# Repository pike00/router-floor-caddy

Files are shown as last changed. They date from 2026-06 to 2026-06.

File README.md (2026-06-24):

---
title: "Router Floor Caddy — Xfinity XB8 + Netgear Orbi RBR850"
description: "A well-ventilated, floor-standing caddy that holds two hot-running networking towers upright, with a bay for incoming-cable entry (\"cabinet input\") and storage (power bricks, cable…"
date: 2026-06-05
version: v3.2
tags: [organization, electronics, storage]
material: PETG / PLA
print: { layer_height: 0.2mm, infill: 20%, supports: false }
license: CC-BY-NC-4.0
showcase: false
source: private
---

# Router Floor Caddy — Xfinity XB8 + Netgear Orbi RBR850

A well-ventilated, floor-standing caddy that holds two hot-running networking
towers upright, with a bay for incoming-cable entry ("cabinet input") and
storage (power bricks, cable slack). Honeycomb-vented walls, open tops.

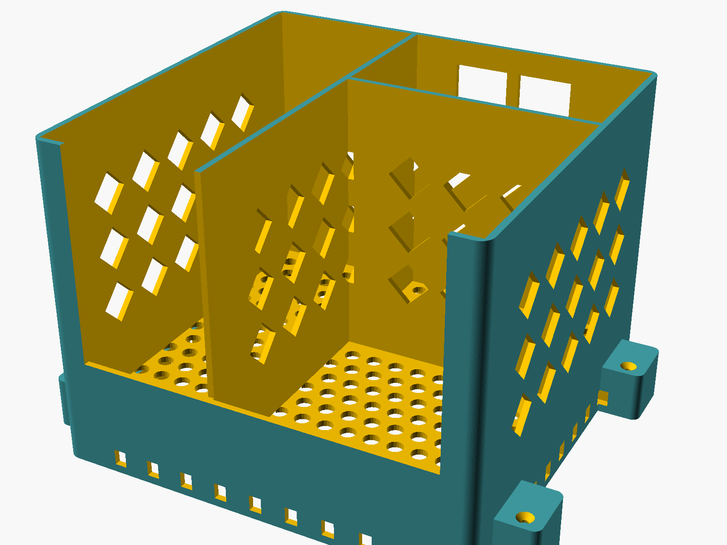
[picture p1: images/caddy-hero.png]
caddy


## Two parts: body + floor-mount base

Prints as **two parts** (both fit a 256 mm bed):

- **`caddy-body.stl`** — the caddy shell with three internal bays (the box).
- **`caddy-base.stl`** — a low vented ring that screws to the floor; the body
  drops onto it and screws down separately, so the body is removable while the
  base stays floor-mounted.

**Installation:** screw the base to the floor through the 4 corner ears
(countersunk #8 holes). Set the body on the base — its 4 corner ears drop over
the base's **conical alignment posts** (the cones self-center the body). Drive an
M3 screw down through each body ear into the post (self-tapping pilot). To remove
the body later, back out the 4 M3 screws; the base stays put.
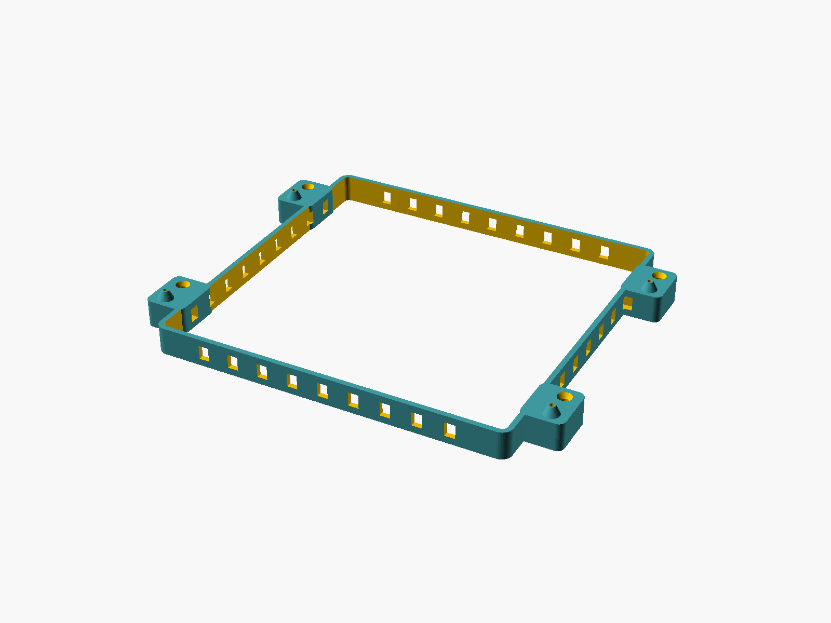
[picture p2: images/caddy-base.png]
base


The whole joint is **support-free**: the cones self-support (sloped walls),
holes are vertical, and every countersink opens upward.

## The box

The body is a single shell with three internal bays, footprint **206 × 200 mm**
(246 mm across the mount ears), ~143 mm tall.

The trick that makes one piece possible: the two routers side-by-side would span
117 + 190 = 307 mm (over the bed), so the **Orbi is rotated 90°** — its thin
72 mm edge faces sideways instead of its 190 mm face. Both towers plus a storage
bay then pack into 206 × 200 mm. The storage/cable bay tucks into the depth gap
behind the shorter XB8:

```
 plan view (one shell, ~206 x 200 mm):
 +-----------+------------------+
 |           |   XB8 bay        |  front wall lowered (drop-in access)
 |  Orbi bay | ports v 117x117  |
 | (rotated) +---[pass]---------+   <- XB8 cables drop into storage
 | ports >   | storage + cable  |  back wall: cable-entry notch
 |  72 x 190 |   ^ Orbi cables  |
 +-----------+------------------+
   ports > = Orbi back face points at divider; cable passes into storage
```

## The two devices (measured / datasheet)

| Device | Footprint (W × D) | Height | Shape |
|---|---|---|---|
| Xfinity **XB8** gateway | ~117 × 117 mm | ~218 mm | square rounded-base tower |
| Netgear **Orbi RBR850** | ~190 × 72 mm | ~280 mm | tall leaf/egg tower |

Sources: the [HIDEit XB8 mount](https://hideitmounts.com/products/hideit-xb8-xfinity-xb8-gateway-modem-mount)
cradle is 120 mm square (confirming the ~117 mm XB8 base); Orbi dimensions are
from the Netgear RBK850 datasheet (11.02 × 7.50 × 2.81 in). Each bay is a
rectangular pocket sized to the device footprint + 2 mm clearance per side; the
Orbi's curved leaf sits loosely in its rectangular pocket (add a strip of foam if
you want a snug grip). No floor-caddy STL for these exists online — every hit is
a *wall* mount (e.g. [XB8](https://www.printables.com/model/414508-xfinity-gateway-xb8-wall-mount),
[Orbi](https://www.printables.com/model/48893-orbi-mount-for-rbr850-router-and-satellite)) —
so this is modeled from dimensions, not remixed.

Each bay grips only the lower ~half of its tower; the towers protrude above the
open tops, fully exposed for cooling. The **front wall is lowered to 35 mm** for
cable/port access and heat relief.

## Ventilation

- Hex-staggered perforated **floor** under every bay.
- **12 mm raised feet** → an open air gap under the whole caddy so air enters
  from below and rises through the floor holes and open tops.
- **Diagonal-lattice vents** (45° diamond openings) across the outer side/back
  walls AND both internal divider walls, so air (and cables) move freely between
  all three bays. Every opening peaks at 45°, so the walls have **no horizontal
  bridges at all** — the most support-free vent pattern.
- The **base ring** is slot-vented; air enters its sides, rises through the
  body's hex floor and out the open tops.
- **Open tops**; towers stand exposed above the shell line.

## Cable input + storage + router orientation

The central rear bay is the **cabling hub**. It has a **cable window in the back wall** (closed at the top by a rim bar so the wall sections beside it are tied together, not free-topped flaps)
for incoming coax/ethernet (the "cabinet input") and holds power bricks,
splitters, and cable slack.

**Both routers face their port (back) sides into this bay:**

- The **Orbi** is rotated so its port/broad face points at the **+X divider**;
  a low cable pass-through in that divider drops its cables into the storage bay.
- The **XB8** faces its ports at the **+Y divider** into the same bay through a
  matching low pass-through.

So every cable runs into the central bay and out the rear notch — nothing is
boxed against an outer wall. Directionality note: rotating the Orbi about its
vertical axis does **not** affect cooling (convection is bottom-to-top) or WiFi,
but it does move its port/vented broad face — hence the deliberate
divider-facing layout and the extra vents cut into the divider beside it.

## Printing

- **Material: PETG** recommended — it sits on a floor next to two warm devices;
  PETG tolerates heat far better than PLA. PLA works if the room stays cool.
- 0.2 mm layers, 15–20 % infill, 3 walls.
- **No supports needed** — walls are vertical; hexagons, hex floor holes, and the
  cable window all bridge fine; the base slots are tiny bridges.
- Print as exported: each part floor-down, open side up.
- Two prints (body + base), each ~246 × 200 mm — fit a 256 mm bed.
- **Hardware:** 4 × #8 wood/floor screws (base → floor) + 4 × M3 × ~12 mm
  self-tapping screws (body → base posts).

## Build

```sh
just build      # export caddy-body.stl + caddy-base.stl
just preview    # re-render the PNGs in images/  (uses xvfb-run)
just clean      # remove generated STLs
```

`src/caddy.scad` is the parametric source of truth — every dimension is a named
parameter at the top (device footprints, clearance, wall/shell height, storage
depth, vent sizing, and the base/ear/screw dimensions). `part="body"|"base"|
"assembly"` selects what to emit; change a parameter and re-run `just build`.

## Versions

- **v3.2** — wall + divider vents switched from honeycomb to a **45° diagonal
  lattice** (diamond openings). Every opening peaks at 45°, so there are no
  horizontal bridges — the most support-free vent pattern.
- **v3.1** — fully support-free: the body↔base joint uses **conical self-centering
  posts** (no blind sockets/overhangs); the cable window gets a center mullion so
  its rim is a short bridge; and **both internal divider walls are honeycombed**
  for cross-bay ventilation + cable passage.
- **v3** — split into **body + floor-mount base** (base screws to floor; body
  aligns on posts and screws down separately) and switched wall vents to a
  **honeycomb** lattice (angular, strong, print-friendly).
- **v2.7** — wall vents tuned to a diagonal lattice/trellis (thin 45° ribs,
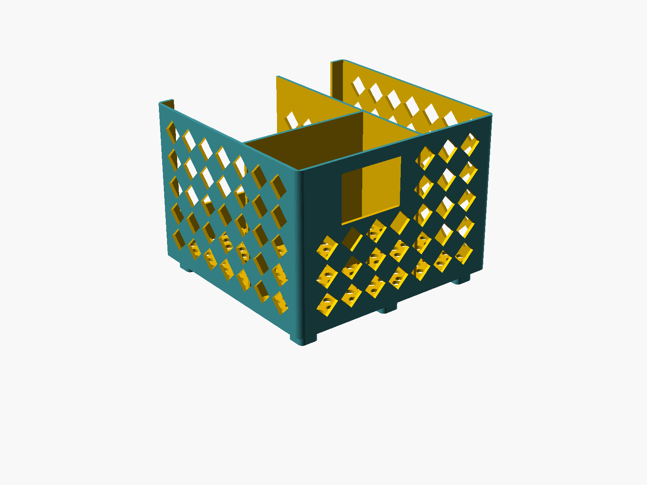
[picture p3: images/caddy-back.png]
back
  larger openings, fuller wall coverage). 
- **v2.6** — wall vents restyled from vertical slots to a diamond pattern
  (outer walls + dividers); floor stays hex, cable window keeps its clean border.
- **v2.5** — restored the back vent slots and shifted the cable window onto the
  slot grid so it keeps ~8 mm wall on each side (removed the thin sliver without
  deleting any slits). *(slots later replaced by diamonds in v2.6.)*
- **v2.4** — re-export at `$fn=64` (final smoothness).
- **v2.3** — kept back vent slots clear of the cable window (superseded by v2.5).
- **v2.2** — back cable cutout closed at the top with a rim bar (`back_rim`),
  so the wall sections flanking it are tied top and bottom instead of being
  free-topped flaps.
- **v2.1** — cabling fix: both routers' port faces aimed into the central
  storage bay via low divider pass-throughs; extra vents in the divider beside
  the Orbi's broad face. Same footprint, still one print.
- **v2** — single-piece unified box: one shell, three internal bays (Orbi
  rotated 90°, XB8, storage + cable notch), fits a 256 mm bed in one print.
- **v1** — three separate dovetail-together tiles (superseded; the assembled
  footprint was the same but it was three prints, not one).

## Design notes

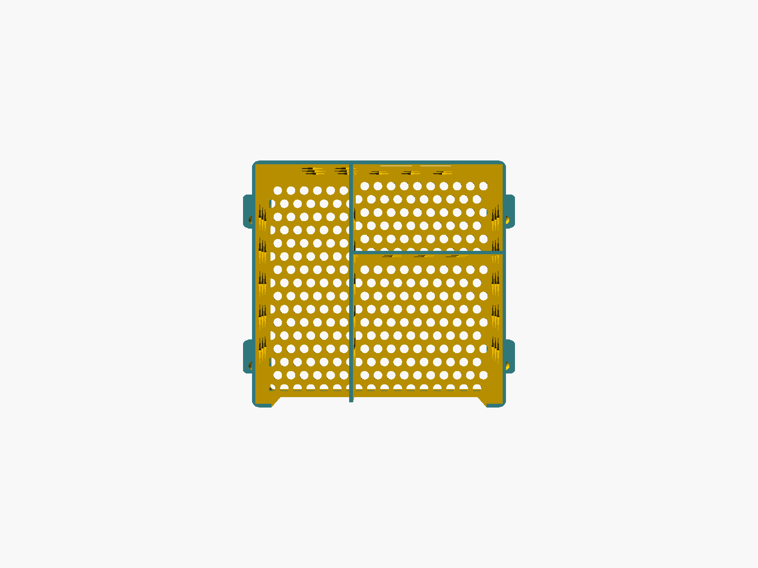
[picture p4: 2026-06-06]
images/caddy-top.png

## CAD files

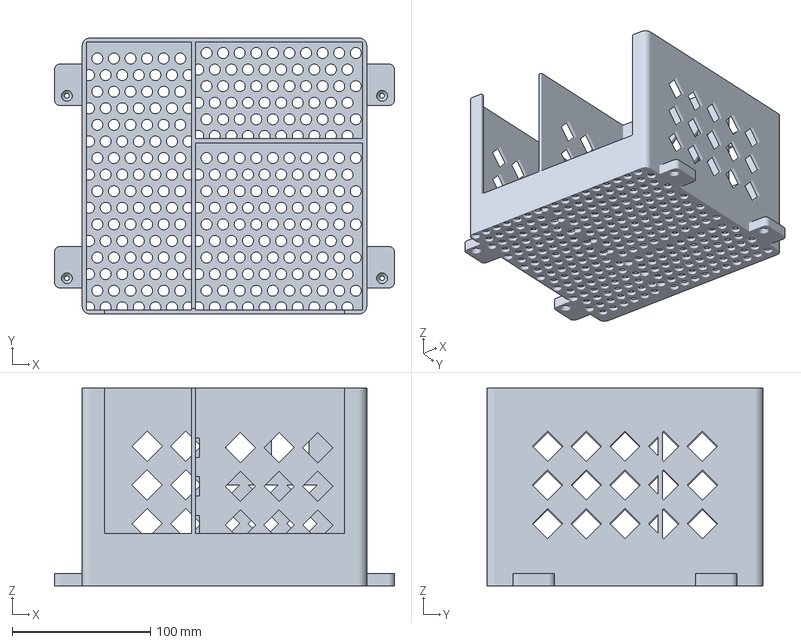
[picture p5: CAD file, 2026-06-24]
export/caddy-body.3mf
246.0 x 200.0 x 143.0 mm

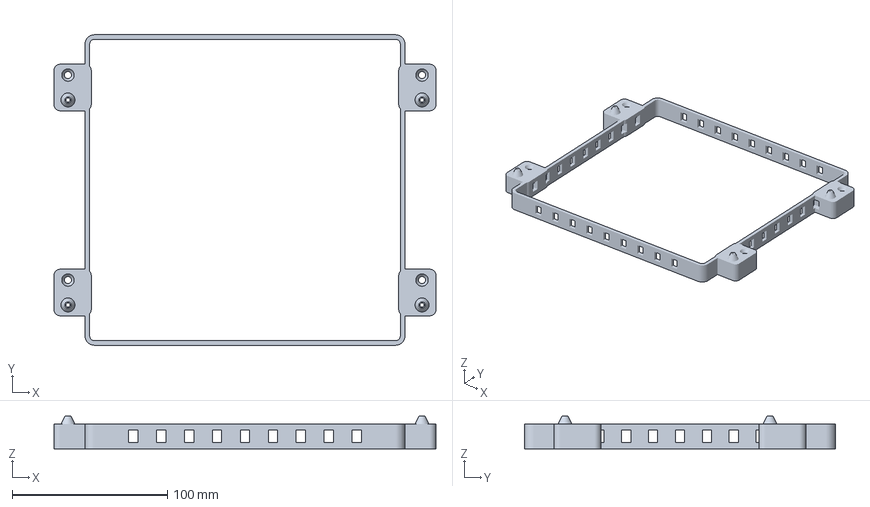
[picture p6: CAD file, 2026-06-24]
export/caddy-base.3mf
246.0 x 200.0 x 21.0 mm

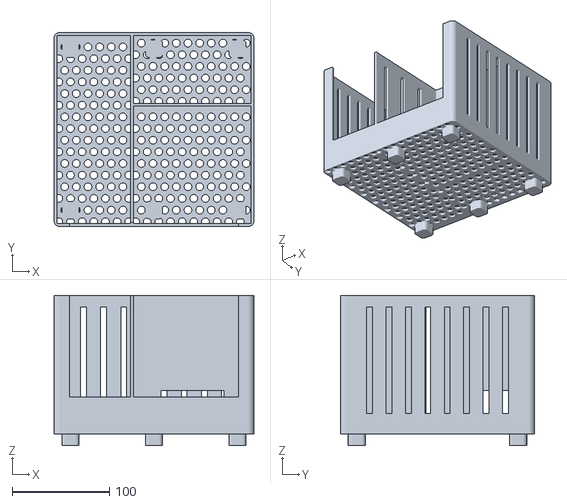
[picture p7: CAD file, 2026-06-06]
export/caddy.stl
206.0 x 200.0 x 155.0

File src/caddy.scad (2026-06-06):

// Router floor caddy — Xfinity XB8 + Netgear Orbi RBR850
// SINGLE-PIECE vented floor box: one shell, three internal bays, prints whole.
//
//   Orbi is rotated 90deg (thin 72mm edge sideways) so both towers + a storage
//   bay pack into a ~206 x 200 mm footprint that fits a 256 mm bed in one print.
//
//   export:  openscad -o export/caddy.stl src/caddy.scad
//
// Coordinates: X = width, Y = depth (front = -Y, lowered for access; back = +Y,
// cable entry), Z = up. Towers stand in vented bays and protrude above the open
// tops, fully exposed for cooling.

// ----------------------------- parameters ----------------------------------
$fn = 32;                       // global smoothness (raise for final export)

// fit
clearance = 2;                  // router-to-wall gap, per side (loose insert)

// structure
wall        = 3;                // shell + divider thickness
floor_th    = 3;                // perforated floor thickness
foot_height = 16;               // body standoff = base ring height -> under-caddy air gap
outer_h     = 140;              // shell wall height (grips lower half of towers)
front_lip   = 35;              // front wall lowered to this height for access
plate_r     = 6;                // outer corner radius

// part selector: "body" | "base" | "assembly"
part = "assembly";

// --- floor-mount base split ---
// The caddy splits into a BASE (a vented ring that screws to the floor) and the
// BODY. The base has alignment posts; the body drops over them and is screwed
// down into the posts. Both meet at 4 external corner ears:
//   base ear  : floor-mount screw (down into floor) + alignment post (up)
//   body ear  : socket over the post + screw down into the post's pilot
base_h   = foot_height;         // base ring height (the standoff)
ear      = 20;                  // ear length, sticking outward in X
ear_w    = 30;                  // ear width (Y)
ear_t    = 9;                   // body-ear thickness (Z)
post_d   = 7;                   // base alignment post OD
post_up  = 5;                   // post protrusion into the body ear
m3_clear = 3.4;                 // body->base screw clearance (M3)
m3_pilot = 2.6;                 // self-tap pilot in the post
floor_d  = 4.5;                 // base->floor screw clearance (#8 wood screw)
csk_d    = 8;                   // countersink head diameter

// devices  [width, depth] mm  (measured / datasheet — see README)
xb8_dev  = [117, 117];          // square rounded-base tower, ~218 tall
orbi_dev = [190, 72];           // leaf tower, ~280 tall (rotated 90deg here)

// storage / cable bay (tucked behind the shorter XB8)
storage_d = 70;                 // storage bay depth
cable_slot_w = 60;              // back-wall cable-entry window width
cable_slot_h = 55;              // ... window height
back_rim     = 12;              // solid wall left above the window (rim bar tying the flaps)
cable_slot_cx = 134;            // window center X — tuned to sit between back vent slots
                                // (slot pitch 20mm; 134 leaves ~8mm wall to the flanking
                                // slots so there's no thin sliver, while keeping all slots)
cable_pass_h = 42;              // height of internal divider cable pass-throughs
// Both routers' port faces point INTO the central storage bay:
//   - Orbi port (broad) face -> +X divider, cable drops into the storage bay
//   - XB8 port face -> +Y divider, cable drops into the storage bay
// Storage bay collects both and exits the rear cable notch.

// ----------------------------- derived layout ------------------------------
orbi_ix = orbi_dev[1] + 2*clearance;   // 76  (Orbi rotated: thin edge = X)
orbi_iy = orbi_dev[0] + 2*clearance;   // 194 (broad face runs in depth)
xb8_ix  = xb8_dev[0]  + 2*clearance;   // 121
xb8_iy  = xb8_dev[1]  + 2*clearance;   // 121

W_in = orbi_ix + wall + xb8_ix;        // 200
D_in = max(orbi_iy, xb8_iy + wall + storage_d); // 194
W = W_in + 2*wall;                      // 206 outer
D = D_in + 2*wall;                      // 200 outer
floor_top = foot_height + floor_th;
top = floor_top + outer_h;

// four corner mount ears: [cornerX, cornerY, outward-X sign]
ears = [[0, 34, -1], [0, D-34, -1], [W, 34, 1], [W, D-34, 1]];
function earcx(c) = c[0] + c[2]*8;            // ear tab center X
function eph(c)   = [c[0] + c[2]*11, c[1]-8]; // alignment post / body screw XY
function efh(c)   = [c[0] + c[2]*11, c[1]+8]; // floor-mount screw XY

// bay rectangles in local (corner) coords [x0,y0,x1,y1]
orbi_bay = [wall,            wall, wall+orbi_ix,        wall+orbi_iy];
colB_x0  = wall + orbi_ix + wall;
xb8_bay  = [colB_x0,         wall, colB_x0+xb8_ix,      wall+xb8_iy];
stor_y0  = wall + xb8_iy + wall;
stor_bay = [colB_x0,     stor_y0, colB_x0+xb8_ix,       stor_y0+storage_d];

// ----------------------------- helpers -------------------------------------
module rrect(w, d, r) hull() for (sx=[-1,1], sy=[-1,1])
    translate([sx*(w/2-r), sy*(d/2-r)]) circle(r=r, $fn=48);
module rbox(w, d, h, r) linear_extrude(h) rrect(w, d, r);

// open-top pocket cutter for a bay rect (cuts from floor through the top)
module pocket(b) {
    translate([b[0], b[1], floor_top-0.01])
        cube([b[2]-b[0], b[3]-b[1], outer_h+1]);
}

// hex-staggered round vent holes filling a bay rect (cutter at floor)
module vent_rect(b) {
    r = 4; pitch = 12;
    w = b[2]-b[0]; d = b[3]-b[1];
    cols = ceil(w/pitch); rows = ceil(d/pitch);
    for (i=[0:cols], j=[0:rows]) {
        x = b[0] + 2 + i*pitch + ((j%2==1)? pitch/2 : 0);
        y = b[1] + 2 + j*pitch;
        if (x <= b[2]-2 && y <= b[3]-2)
            translate([x, y, foot_height-0.02]) cylinder(r=r, h=floor_th+0.04, $fn=20);
    }
}

// six raised feet under the plate, z:[0,foot_height]
module feet() {
    fs = 18; ins = 8;
    xs = [ins+fs/2, W/2, W-ins-fs/2];
    ys = [ins+fs/2, D-ins-fs/2];
    for (x = xs, y = ys) translate([x, y, 0]) rbox(fs, fs, foot_height, 4);
}

// 2D diagonal-lattice field: 45-degree diamond holes (diagonal d) on a square
// grid of pitch d+strut, filling a uw x vh area centered on the origin. Every
// opening peaks at 45deg, so the pattern prints with no bridges and no support.
lat_d = 22;                         // diamond opening (diagonal, mm)
lat_strut = 6;                      // rib gap between diamonds
module lattice2d(uw, vh, d, strut) {
    p = d + strut; s = d/sqrt(2);
    nu = ceil(uw/(2*p)) + 1; nv = ceil(vh/(2*p)) + 1;
    for (j = [-nv:nv], i = [-nu:nu]) {
        x = i*p; y = j*p;
        if (abs(x) <= uw/2 - d/2 && abs(y) <= vh/2 - d/2)
            translate([x, y]) rotate(45) square(s, center=true);
    }
}

// diagonal-lattice vents over one outer wall side: side = "back"|"left"|"right".
// The 2D field is mapped onto each wall (vertical axis -> Z). On the back wall
// the field skips the cable-window footprint so the window keeps a clean border.
module wall_lattice(side) {
    t = wall*3;
    z0 = floor_top + 8; z1 = top - 8; V = z1 - z0; zc = (z0 + z1)/2;
    if (side == "back") {
        wkc_z = top - (cable_slot_h + back_rim)/2;      // cable-window center (Z)
        translate([W/2, D, zc]) rotate([90,0,0]) linear_extrude(t, center=true)
            difference() {
                lattice2d(W - 26, V, lat_d, lat_strut);
                translate([cable_slot_cx - W/2, wkc_z - zc])
                    square([cable_slot_w + lat_d + 8,
                            (cable_slot_h - back_rim) + lat_d + 8], center=true);
            }
    } else {
        translate([(side=="left") ? 0 : W, D/2, zc]) rotate([0,90,0])
            linear_extrude(t, center=true) lattice2d(V, D - 26, lat_d, lat_strut);
    }
}
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

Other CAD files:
export/caddy-base.stl

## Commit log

2026-06-06 v1: 3-tile dovetail floor caddy for XB8 + Orbi RBR850
    Modular vented open-stand caddy: Orbi cradle, XB8 cradle, and a cable-input
    + storage tray that dovetail together (no hardware). Each tile fits a 256mm
    bed. Parametric OpenSCAD source; hex-vented floors, slotted walls, raised
    feet, lowered front access, back-wall cable notch.
    [caddy.scad, orbi-cradle.stl, storage-tray.stl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]
2026-06-06 v2: single-piece unified box (Orbi rotated 90deg to fit 256mm bed)
    Replaces the 3-tile dovetail design with one shell holding three internal
    bays: Orbi (rotated so its thin edge fits), XB8, and a storage+cable bay.
    Footprint 206x200x155mm, prints whole on a 256mm bed. Shared hex-vented
    floor, slot side vents, lowered front access, back cable notch, raised feet.
    [caddy.scad, caddy.stl, orbi-cradle.stl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]
2026-06-06 v2.1: aim both router ports into central storage bay
    Orbi port face -> +X divider, XB8 port face -> +Y divider, each with a low
    cable pass-through into the shared storage bay so all cabling consolidates
    and exits the rear notch. Added vents to the divider beside the Orbi broad
    face (rotating the Orbi moves its vented/port face, so it gets airflow too).
    [caddy.scad, caddy.stl]
2026-06-06 v2.2: close back cable cutout top with a rim bar
    The back cable cutout was open at the top, leaving the flanking wall
    sections held only at the bottom (free-topped flaps). Leave a 12mm rim
    band of wall above the window so it becomes a closed port that ties both
    sides together top and bottom. Adds a back-view render.
    [caddy.scad, caddy.stl]
2026-06-06 v2.3: keep back vent slots clear of the cable window
    The back vent slots ran up against the cable window, leaving paper-thin
    wall slivers beside it and a comb of slot-teeth below it. Skip any back
    slot within 8mm of the window span so the window sits in clean solid wall.
    [caddy.scad, caddy.stl]
2026-06-06 v2.4: re-export caddy.stl at $fn=64 (final smoothness)
    [caddy.stl]
2026-06-06 v2.5: restore back vent slots; shift cable window onto slot grid
    Reverts the v2.3 slot removal (slits are back) and instead positions the
    cable window (cable_slot_cx) between back vent slots so it keeps ~8mm wall on
    each side -- removes the thin sliver without deleting any slots. STL re-exported
    at $fn=64.
    [caddy.scad, caddy.stl]
2026-06-06 v2.6: diamond-lattice wall vents
    Replace the vertical slot vents on the outer walls (back/left/right) and the
    +X divider with a 45deg diamond lattice (self-supporting, no bridging). Floor
    keeps its hex perforation; the back lattice skips the cable-window footprint so
    the window keeps a clean border. STL re-exported at $fn=64.
    [caddy.scad]
2026-06-06 v2.7: tune wall vents to a diagonal lattice/trellis
    Thin 45-degree ribs with larger diamond openings and fuller wall coverage
    (d=22, strut=3) so the walls read as a lattice rather than a field of
    diamond holes. STL re-exported at $fn=64.
    [caddy.scad]
2026-06-06 v3: split into body + floor-mount base; honeycomb walls
    - Wall vents switched to a honeycomb lattice (angular, strong, print-friendly).
    - Split into two printed parts:
    - caddy-base.stl: a vented ring that screws to the floor (4 countersunk
    corner ears) with alignment posts on top.
    - caddy-body.stl: the caddy; drops over the base posts (4 corner ears with
    sockets) and screws down into them with M3 self-tappers. Removable.
    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
    [caddy-base.stl, caddy.scad]
2026-06-06 v3.1: support-free conical joint, vented internal walls, window mullion
    - Body<->base joint now conical: a self-centering cone post (base) into a cone
    socket (body) instead of a cylindrical blind socket -> no flat ceilings, no
    support needed; cones also self-center the body on the base.
    - Both internal divider walls (Orbi|colB and XB8|storage) fully honeycombed for
    cross-bay ventilation; bottom cells double as cable pass-throughs (replaces
    the old rectangular passes and their bridges).
    - Cable window split by a center mullion so the rim bar is a short bridge.
    STLs re-exported at $fn=64.
    [caddy-base.stl, caddy.scad]
2026-06-06 v3.2: 45-degree diagonal lattice wall/divider vents (no bridges)
    Replace the honeycomb vents with a 45-degree diamond lattice on all outer
    walls and both internal dividers. Diamond openings peak at 45deg so there are
    no horizontal bridges anywhere -> fully support-free. Floor stays hex; cable
    window keepout preserved. STLs re-exported at $fn=64.
    [caddy-base.stl, caddy.scad]
2026-06-24 feat: showcase frontmatter, CC-BY-NC license, derived GLB+3MF
    Phase 1+2 of the prints.pikemd.com showcase pipeline: README YAML frontmatter (the showcase contract; showcase:false until curated), a CC-BY-NC-4.0 LICENSE, and centralized web GLB + manufacturing 3M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
    [caddy-base.3mf, caddy-body.3mf]
